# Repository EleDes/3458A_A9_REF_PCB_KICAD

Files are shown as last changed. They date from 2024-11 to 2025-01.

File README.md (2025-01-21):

# 3458A A9 Reference board in KiCad

REV B - build & verified

[3458A Ref A9 Schematics](Fabrication/3458A%20Ref%20A9%20Clone.pdf?raw=true "3458A Ref A9 Schematics")
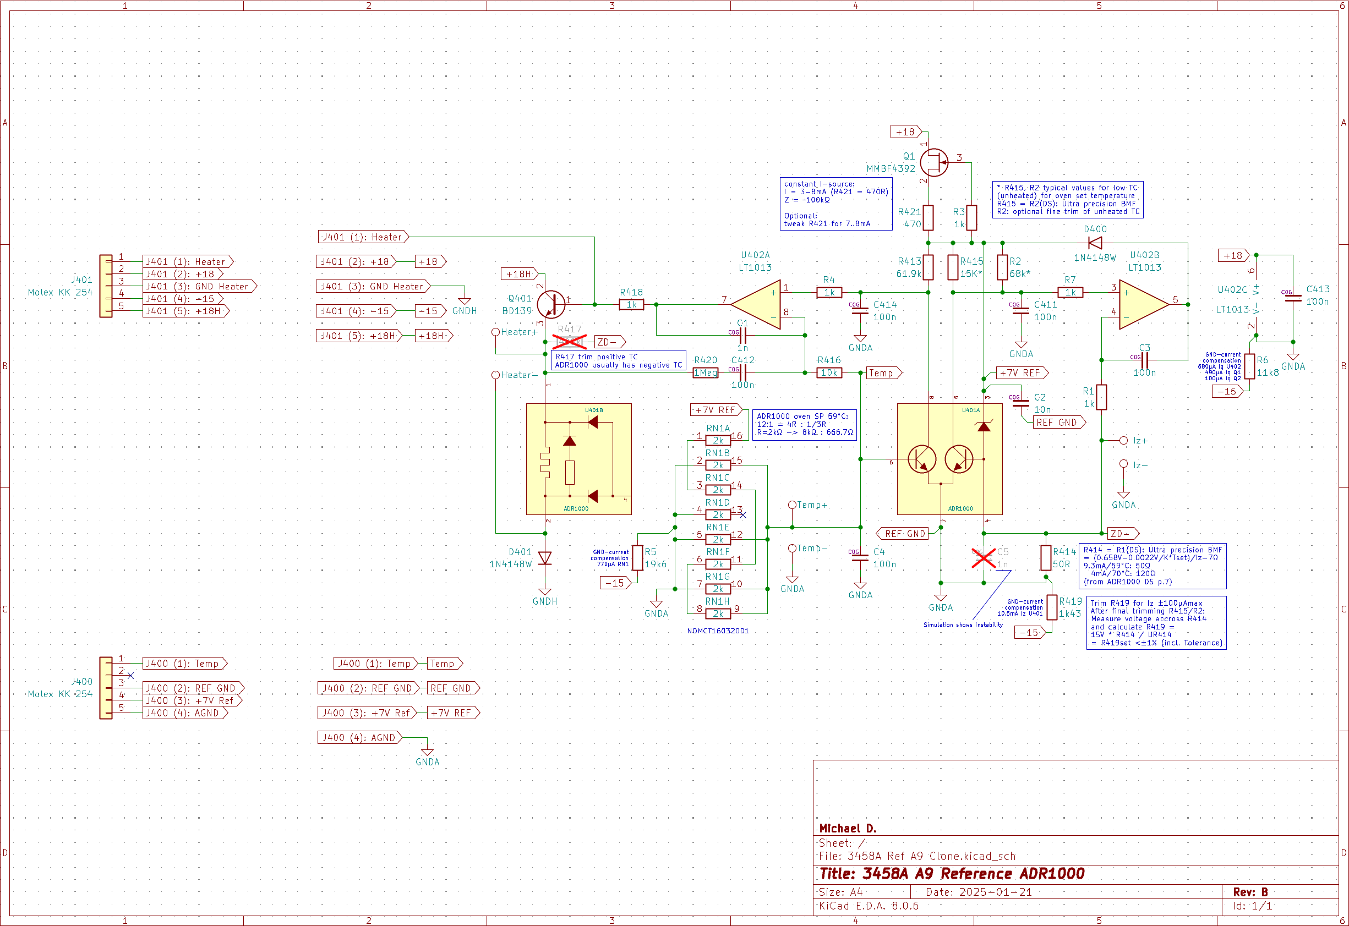
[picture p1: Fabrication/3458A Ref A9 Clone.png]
3458A Ref A9 Schematics


[3458A Ref A9 BOM (interactive)](https://htmlpreview.github.io/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 "3458A Ref A9 BOM (interactive)")

[3458A Ref A9 Gerber](gerber/ "3458A Ref A9 Gerber")

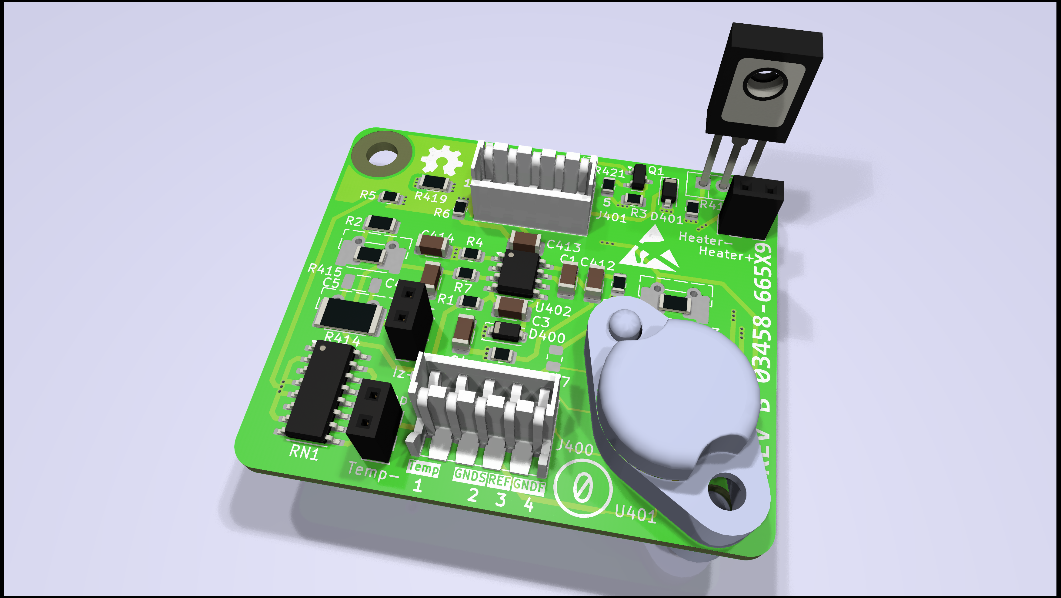
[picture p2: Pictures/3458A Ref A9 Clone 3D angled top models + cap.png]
3458A Ref A9 3D angled top models + cap


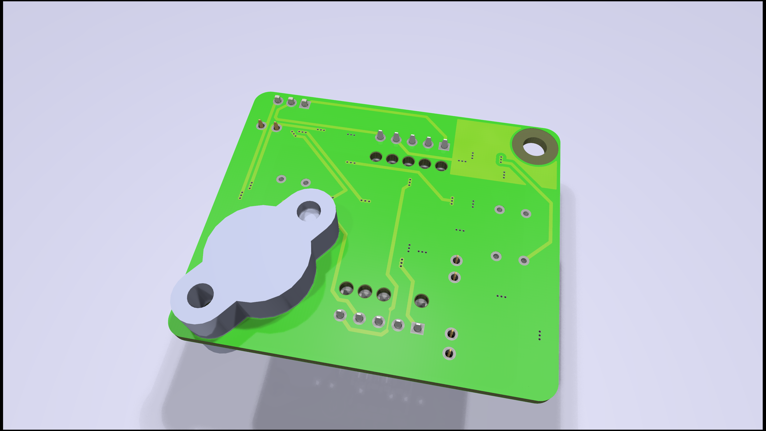
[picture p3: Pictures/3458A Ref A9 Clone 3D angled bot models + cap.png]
3458A Ref A9 3D angled bot models + cap


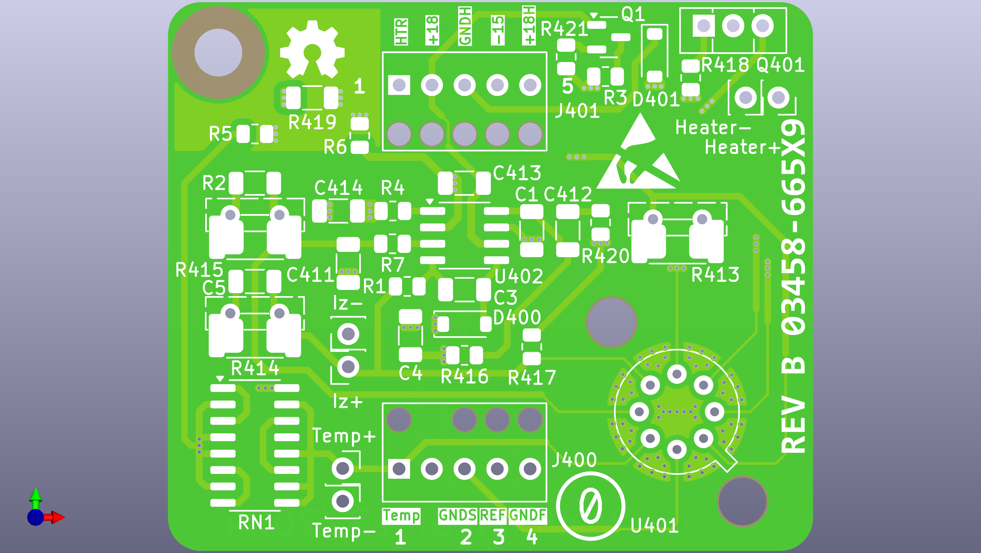
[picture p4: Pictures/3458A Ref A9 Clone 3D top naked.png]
3458A Ref A9 3D top


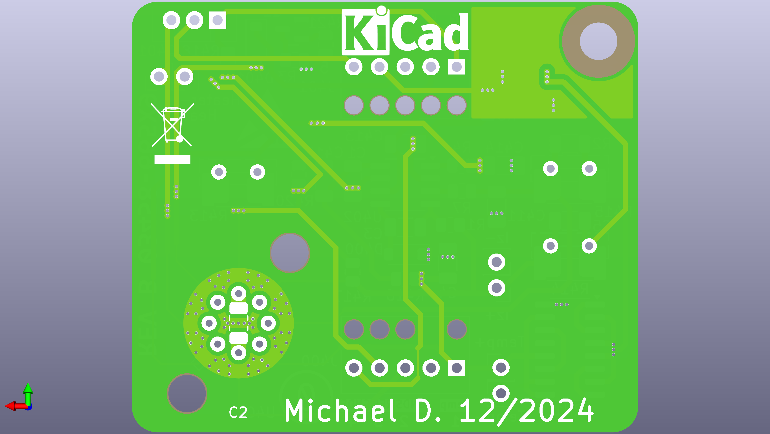
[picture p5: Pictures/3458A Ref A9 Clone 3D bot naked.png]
3458A Ref A9 3D bot


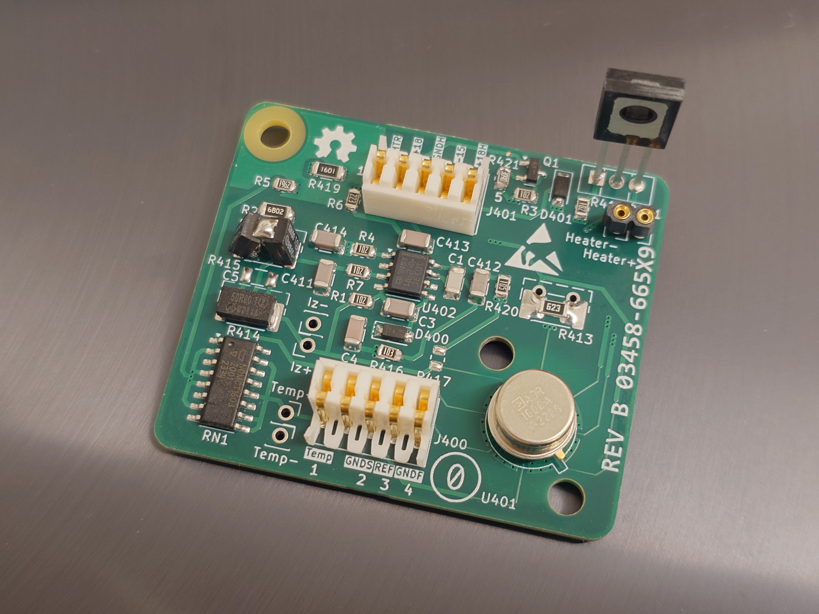
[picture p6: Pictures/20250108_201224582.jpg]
3458A Ref A9 build


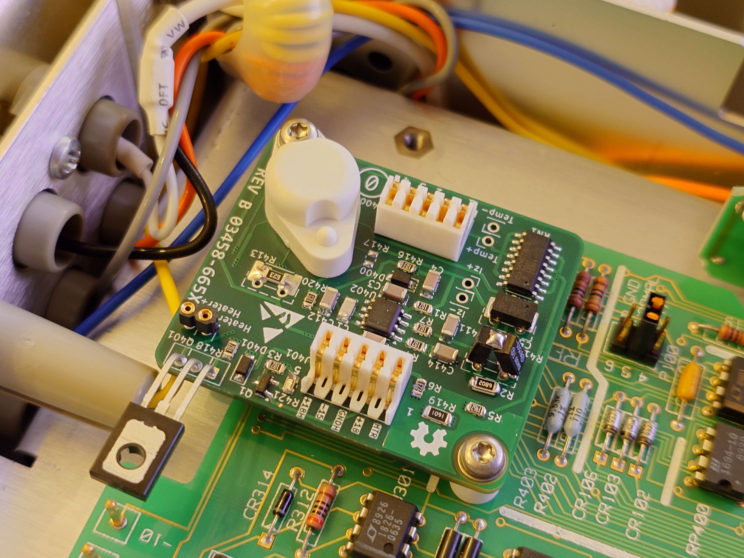
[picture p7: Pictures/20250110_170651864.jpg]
3458A Ref A9 mounted










These 3D models are excluded from project license (folder 3D):

022172052: Molex KK 254 from [https://www.molex.com/en-us/products/part-detail/22172052](https://www.molex.com/en-us/products/part-detail/22172052) - copyright: Molex 

A9_CAP_BOT, A9_CAP_TOP: from [https://xdevs.com/fix/hp3458a/#a9pcba branadic](https://xdevs.com/fix/hp3458a/#a9pcba) - copyright: [https://xdevs.com/fix/hp3458a/#legal](https://xdevs.com/fix/hp3458a/#legal)

TO-5-8pins: from [https://grabcad.com/library/to-5-8-pin-ltz1000-1](https://grabcad.com/library/to-5-8-pin-ltz1000-1) - terms of use: [https://blog.grabcad.com/terms-of-use/](https://blog.grabcad.com/terms-of-use/)

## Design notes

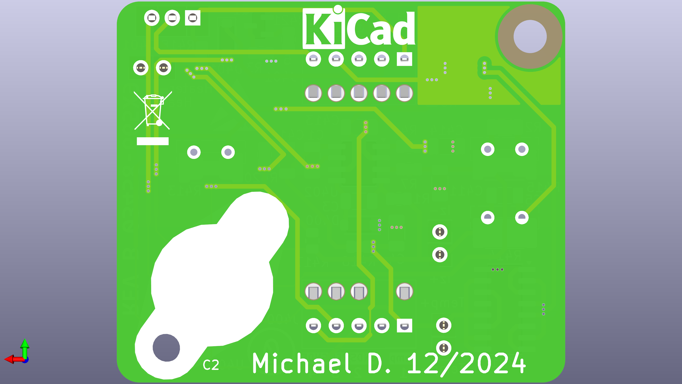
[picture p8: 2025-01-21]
Pictures/3458A Ref A9 Clone 3D bot models + cap.png

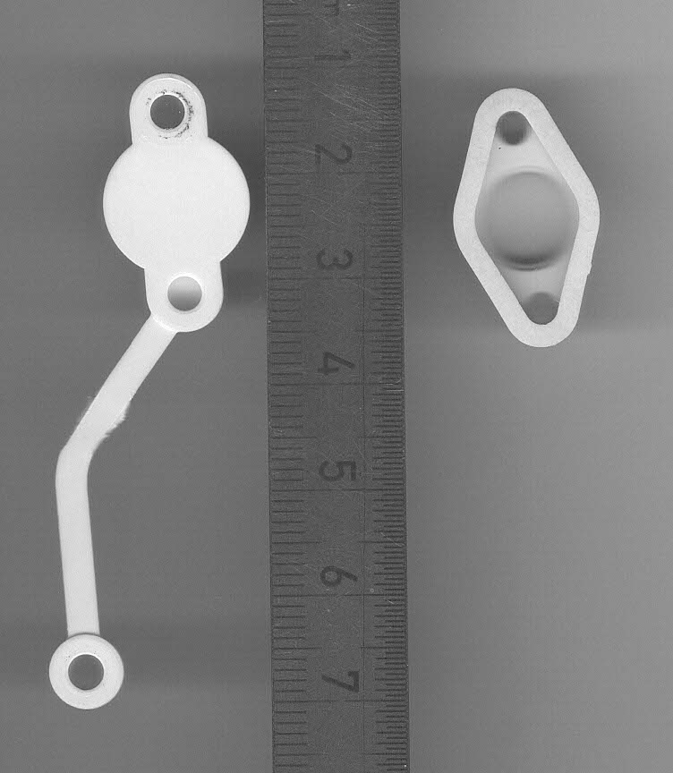
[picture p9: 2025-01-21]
Pictures/A9 Cover top bot.png

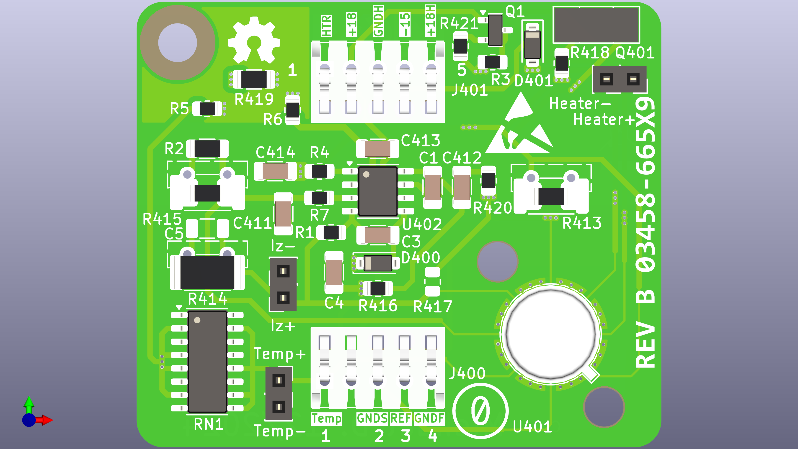
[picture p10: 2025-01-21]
Pictures/3458A Ref A9 Clone 3D top models.png

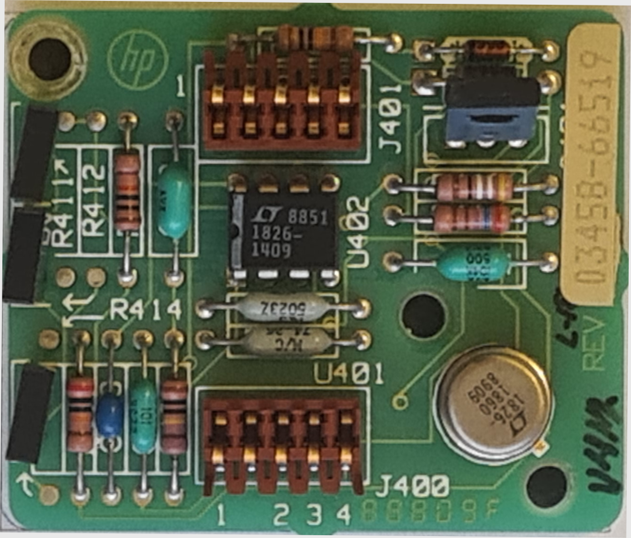
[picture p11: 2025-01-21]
Pictures/20241115_002510_straight.png

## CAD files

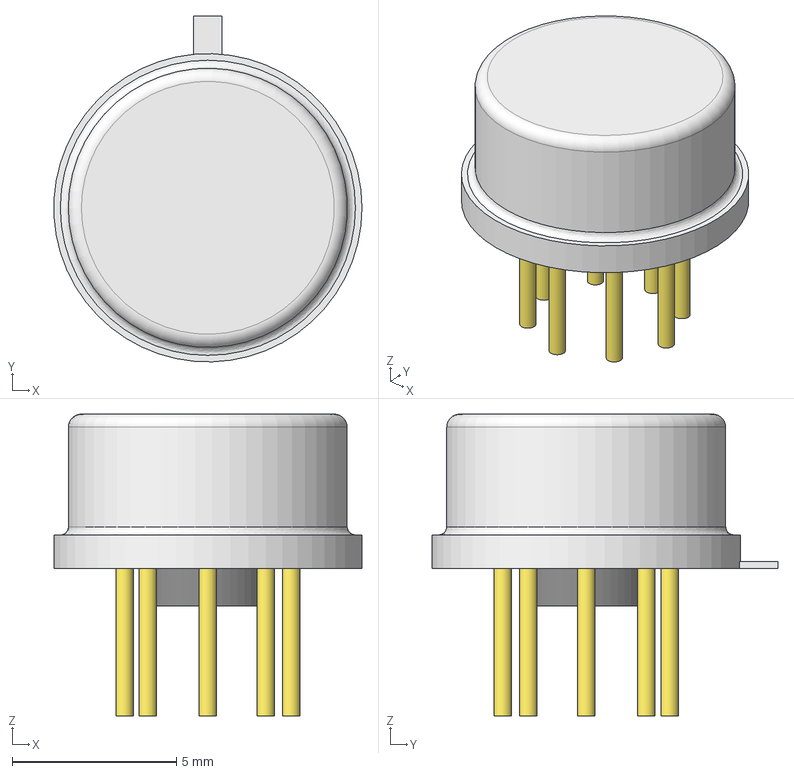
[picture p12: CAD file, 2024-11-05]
3D/TO-5-8pins.step
9.39 x 10.5 x 9.20 mm
Sketch001

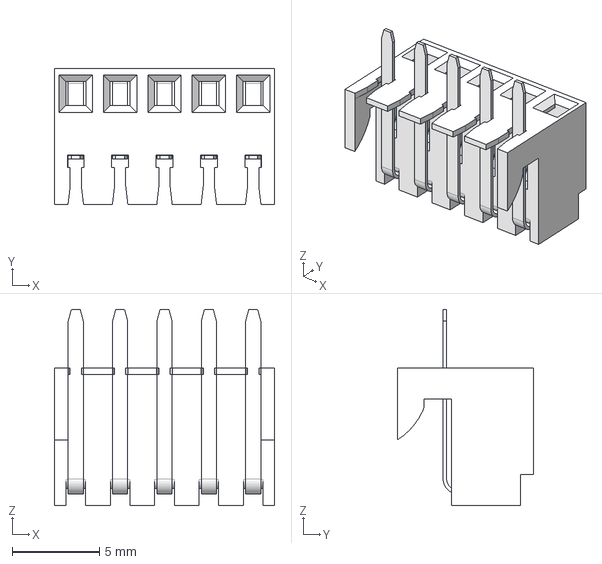
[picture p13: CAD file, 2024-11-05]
3D/022172052.STEP
12.6 x 7.80 x 11.2 mm

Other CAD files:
3D/022172052 transparent.STEP

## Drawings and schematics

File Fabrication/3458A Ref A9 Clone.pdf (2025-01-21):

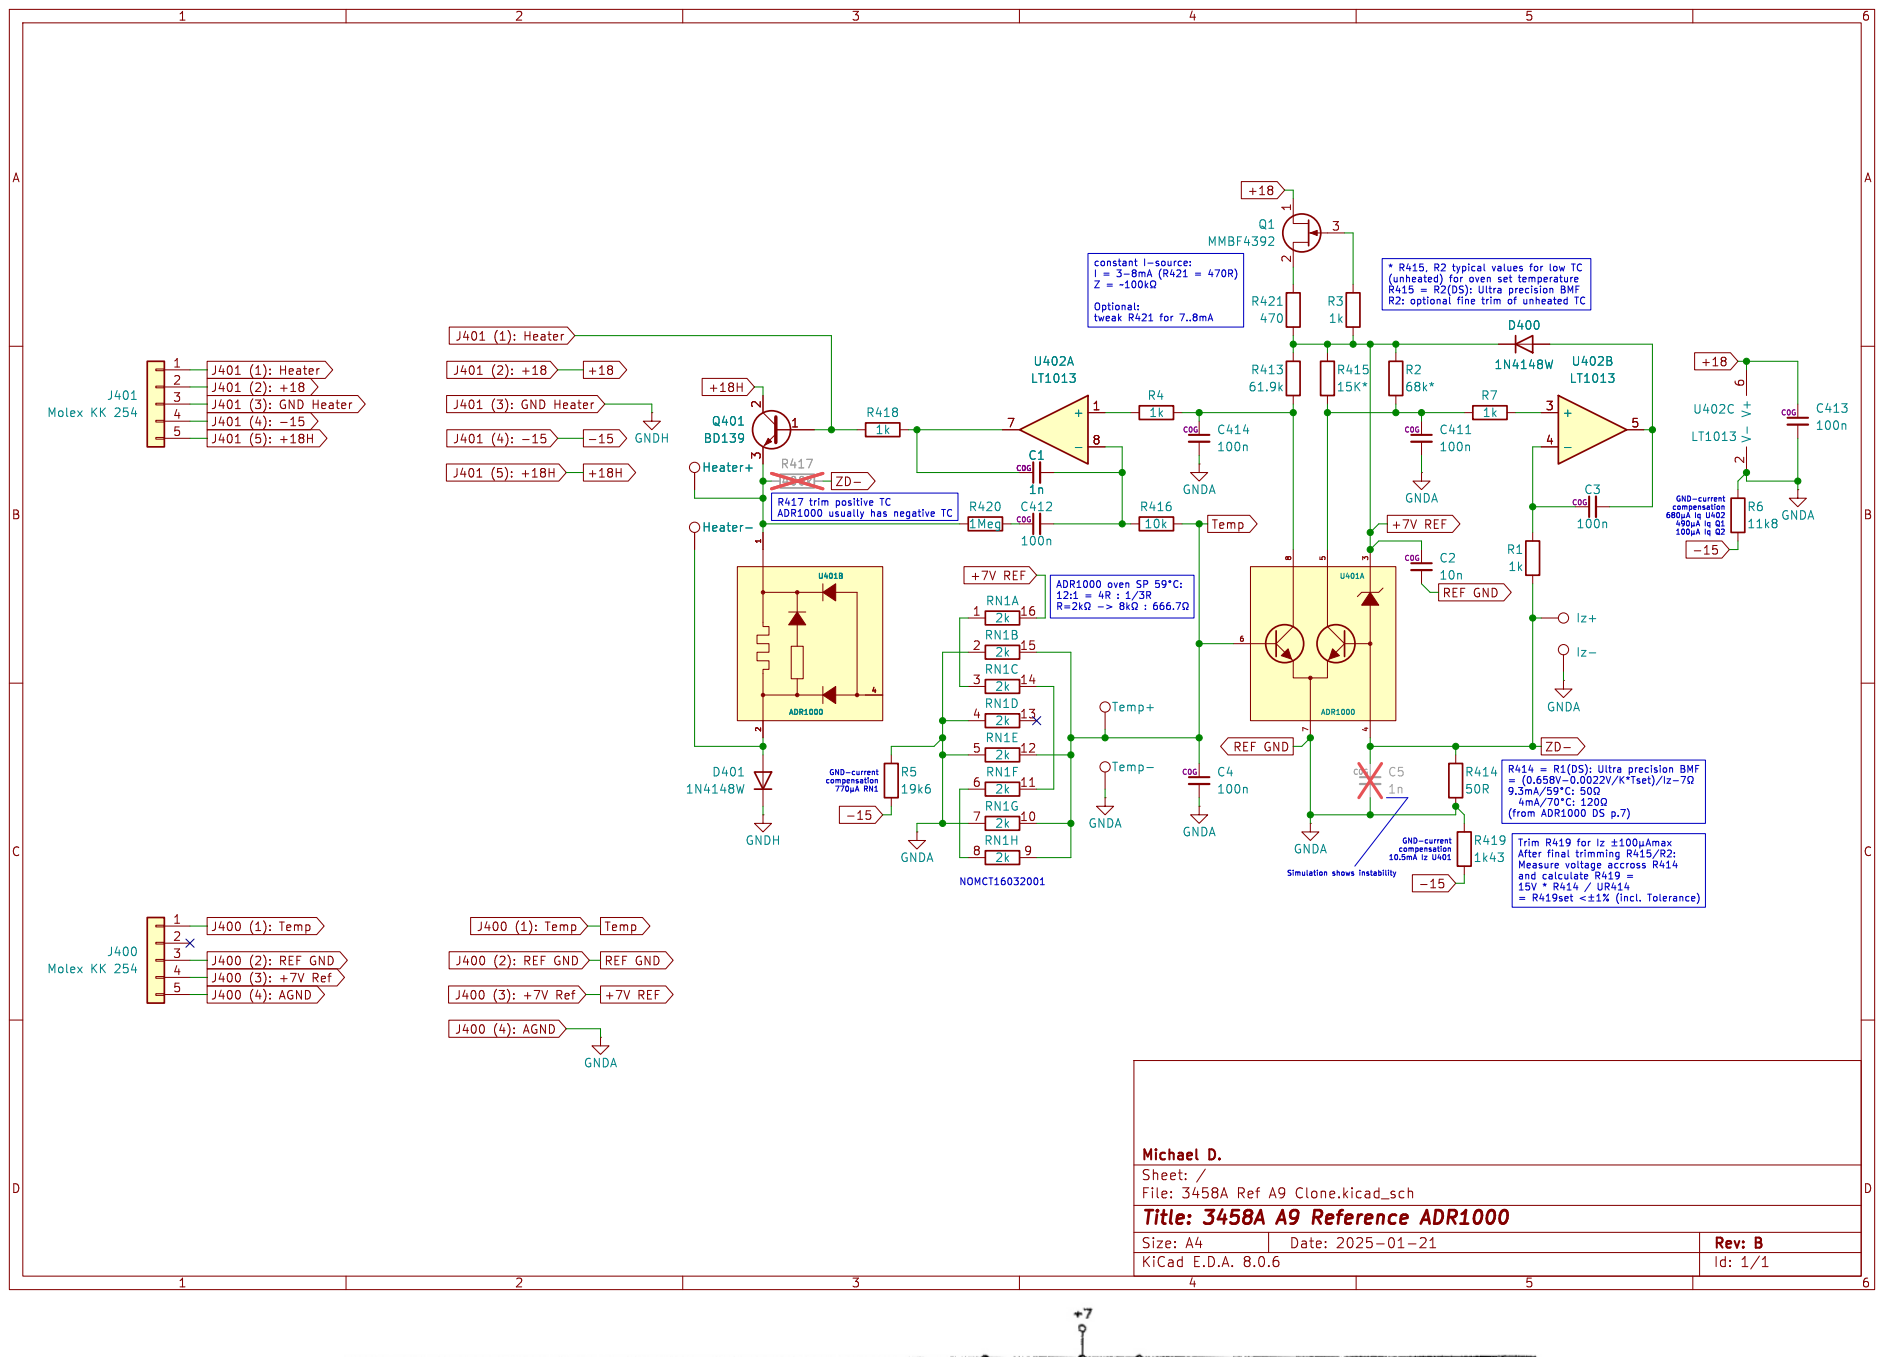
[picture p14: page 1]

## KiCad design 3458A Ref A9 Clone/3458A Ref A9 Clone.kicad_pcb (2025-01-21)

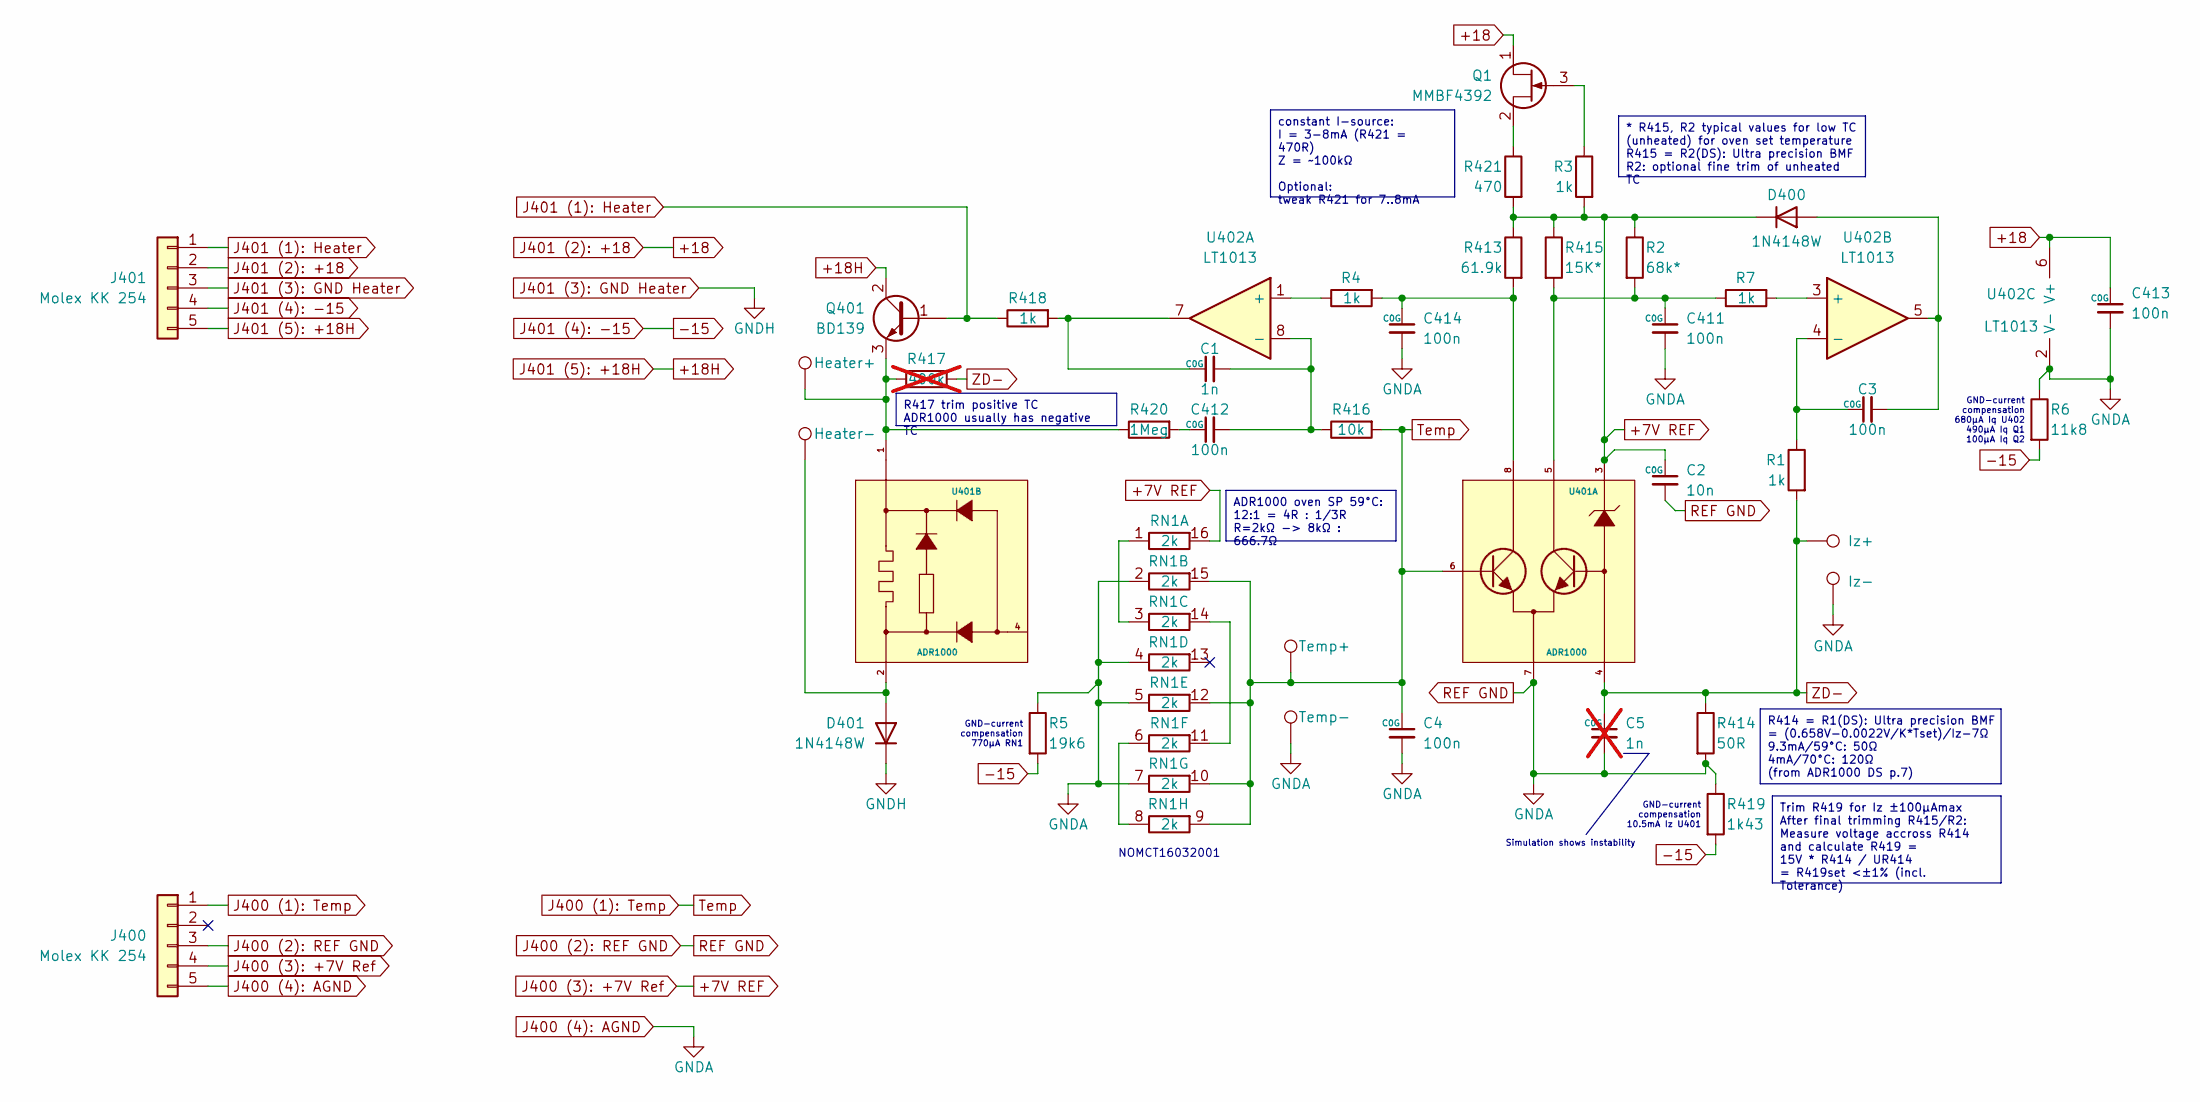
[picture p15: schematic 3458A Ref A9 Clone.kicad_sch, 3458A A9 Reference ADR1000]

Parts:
C1: 1n; C_1206_3216Metric
C2: 10n; C_1206_3216Metric
C3, C4, C411, C412, C413, C414: 100n; C_1206_3216Metric
C5: 1n; C_1206_3216Metric; not fitted
D400, D401: 1N4148W; D_SOD-123
J400, J401: Molex KK 254; Molex 22-17-2052
Q1: MMBF4392; SOT-23
Q401: BD139; TO-126-3_Vertical
R1, R3, R4, R7, R418: 1k; R_0805_2012Metric
R2: 68k*; R_1206_3216Metric
R5: 19k6; R_0805_2012Metric
R6: 11k8; R_0805_2012Metric
R413: 61.9k; R_1206_3216Metric
R414: 50R; R_2512_6332Metric
R415: 15K*; R_1206_3216Metric
R416: 10k; R_0805_2012Metric
R417: 400k; R_0805_2012Metric; not fitted
R419: 1k43; R_1206_3216Metric
R420: 1Meg; R_0805_2012Metric
R421: 470; R_0805_2012Metric
RN1: 2k; SOIC-16_3.9x9.9mm_P1.27mm
TP1: Temp+; PinSocket_1x01_P2.54mm_Vertical
TP2: Temp-; PinSocket_1x01_P2.54mm_Vertical
TP3: Iz+; PinSocket_1x01_P2.54mm_Vertical
TP4: Iz-; PinSocket_1x01_P2.54mm_Vertical
TP5: Heater+; PinSocket_1x01_P2.54mm_Vertical
TP6: Heater-; PinSocket_1x01_P2.54mm_Vertical
U401: ADR1000; TO-5-8
U402: LT1013; SOIC-8_3.9x4.9mm_P1.27mm

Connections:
+7V REF: C2.1, D400.1 (K), J400.4, R2.1, R3.2, R413.1, R415.1, R421.2, RN1.16 (R1.2), U401.3
+18: C413.1, J401.2, Q1.1 (D), U402.6 (V+)
+18H: J401.5, Q401.2 (C)
-15: J401.4, R5.2, R6.2, R419.2
J400 (1): Temp: C4.1, J400.1, R416.2, RN1.9 (R8.2), RN1.10 (R7.2), RN1.12 (R5.2), RN1.15 (R2.2), TP1.1, U401.6
J400 (2): REF GND: C2.2, C4.2, C5.2, C411.2, C413.2, C414.2, J400.3, J400.5, R5.1, R6.1, R414.2, R419.1, RN1.2 (R2.1), RN1.4 (R4.1), RN1.5 (R5.1), RN1.7 (R7.1), TP2.1, TP4.1, U401.7, U402.2 (V-)
J401 (1): Heater: J401.1, Q401.1 (B), R418.1
J401 (3): GND Heater: D401.1 (K), J401.3
unnamed: C1.1, R418.2, U402.7
unnamed: C411.1, R2.2, R7.1, R415.2, U401.5
unnamed: C412.1, R420.2
unnamed: C414.1, R4.2, R413.2, U401.8
unnamed: C3.2, D400.2 (A), U402.5
unnamed: D401.2 (A), TP6.1, U401.2
unnamed: Q1.3 (G), R3.1
unnamed: Q1.2 (S), R421.1
unnamed: Q401.3 (E), R417.1, R420.1, TP5.1, U401.1
unnamed: RN1.1 (R1.1), RN1.3 (R3.1)
unnamed: RN1.11 (R6.2), RN1.14 (R3.2)
unnamed: RN1.6 (R6.1), RN1.8 (R8.1)
unnamed: R4.1, U402.1 (+)
unnamed: C1.2, C412.2, R416.1, U402.8 (-)
unnamed: R7.2, U402.3 (+)
unnamed: C3.1, R1.1, U402.4 (-)
ZD-: C5.1, R1.2, R414.1, R417.2, TP3.1, U401.4

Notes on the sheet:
ADR1000 oven SP 59°C: 12:1 = 4R : 1/3R R=2kΩ -> 8kΩ : 666.7Ω
R417 trim positive TC ADR1000 usually has negative TC
Trim R419 for Iz ±100µAmax After final trimming R415/R2: Measure voltage accross R414 and calculate R419 = 15V * R414 / UR414 = R419set <±1% (incl. Tolerance)
R414 = R1(DS): Ultra precision BMF = (0.658V-0.0022V/K*Tset)/Iz-7Ω 9.3mA/59°C: 50Ω 4mA/70°C: 120Ω (from ADR1000 DS p.7)
constant I-source: I = 3-8mA (R421 = 470R) Z = ~100kΩ Optional: tweak R421 for 7..8mA
* R415, R2 typical values for low TC (unheated) for oven set temperature R415 = R2(DS): Ultra precision BMF R2: optional fine trim of unheated TC
Simulation shows instability
GND-current compensation 770µA RN1
NOMCT16032001
GND-current compensation 10.5mA Iz U401
GND-current compensation 680µA Iq U402 490µA Iq Q1 100µA Iq Q2

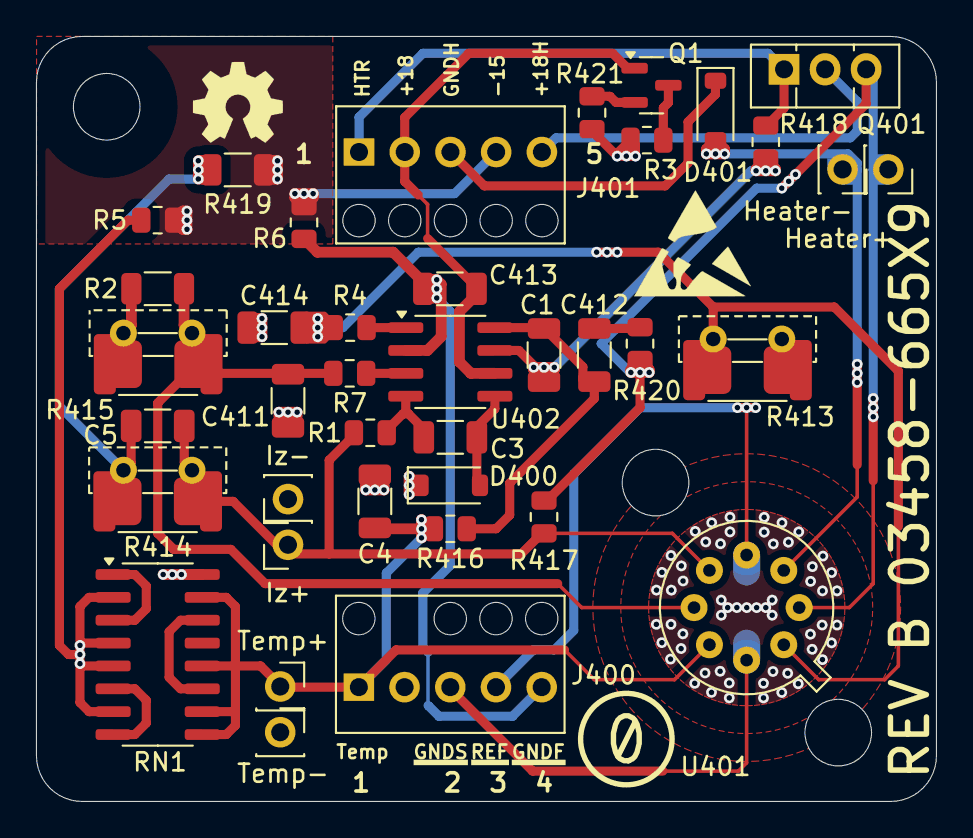
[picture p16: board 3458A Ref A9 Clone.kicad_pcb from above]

Board: 4 copper layers, 50.0 x 42.5 mm, 40 parts (1 on the bottom side), 25 nets.

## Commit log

2024-11-06 fixed README BOM
2024-11-19 Update to REV β
    [3458A Ref A9 Clone-B_Cu.gbr, 3458A Ref A9 Clone-B_Mask.gbr, 3458A Ref A9 Clone-B_Paste.gbp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]
2024-11-19 Rev β for readme
2024-11-19 Readme: direct link to schematic image
2024-11-20 Update to REV A
    [3458A Ref A9 Clone-B_Cu.gbr, 3458A Ref A9 Clone-B_Mask.gbr, 3458A Ref A9 Clone-B_Paste.gbp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]
2025-01-21 Release REV B
    [3458A Ref A9 Clone-B_Cu.gbr, 3458A Ref A9 Clone-B_Mask.gbr, 3458A Ref A9 Clone-B_Paste.gbp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]
